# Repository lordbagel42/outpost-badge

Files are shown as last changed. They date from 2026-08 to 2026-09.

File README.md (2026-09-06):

# Outpost badges!



These are e-ink badges that I made for Outpost! They're built with the RP2354 and have an onboard e-ink driver - I also did the art on it :D

Includes:
- 2.9in e-ink screen
- NFC capabilities
- 6 tactile buttons that snap right onto the board
- 15 additional gpio pins broken out to use with the perfboard at the bottom
- USB-C for power and programming
- 3 lanyard holes that fit single + double clip lanyards, and badge clips
- 4 mounting holes in case you want to 3d print a case - see [`case/`](case/) for a printable one

[Here](https://user-cdn.hackclub-assets.com/019ff91c-0464-7b39-83fa-bce072a783c1/img_1220__yafw_balanced_.mp4) is a video of flappy bird on it! Firmware by [@SamDev-7](https://github.com/SamDev-7)

img_1220__yafw_balanced_

You can also use it to play doom (the badge is only used as a monitor + input in this gif) :D

badgedoomgif

---

### PCB + schematic:




---

HUGE thanks to [@cyao](https://github.com/cheyao) for helping with the design, and ordering the boards! The badge would not have worked without the countless reviews and feedback. 

Additional thanks to [@mpkendall](https://github.com/mpkendall) and [@KaiPereira](https://github.com/KaiPereira) for reviewing the board!

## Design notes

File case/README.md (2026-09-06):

# 3D-printable case for the Outpost badge

A two-part, screw-together case generated straight from the KiCad board file.
Designed for a **0.6 mm nozzle**: nothing in it is thinner than 1 mm, which
`tools/check_walls.py` verifies by slicing the exported STLs.

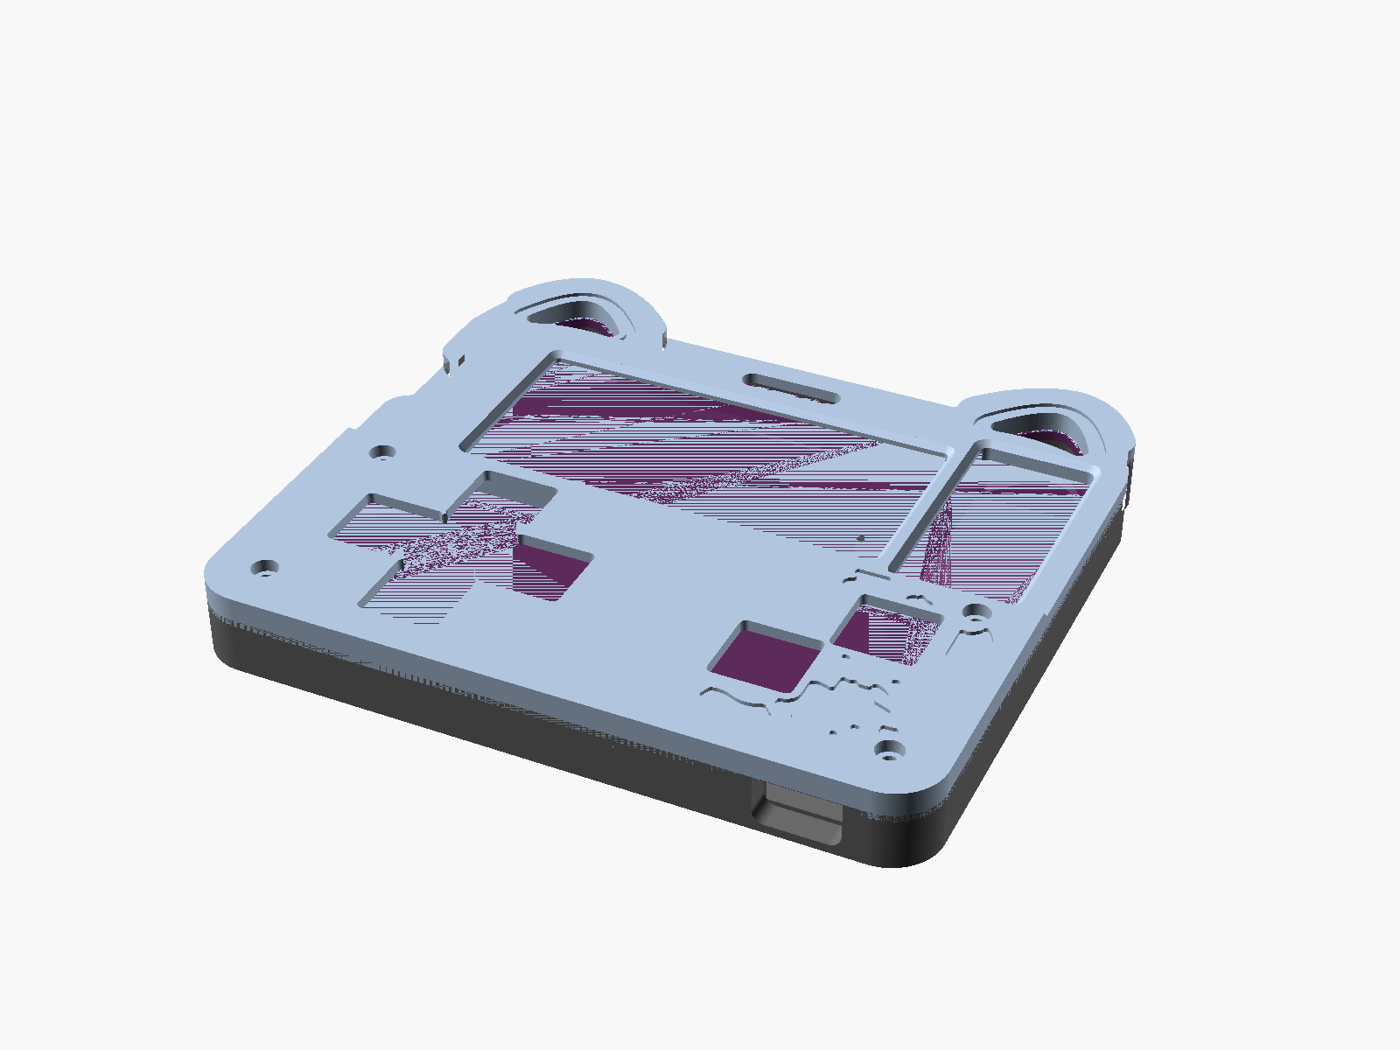
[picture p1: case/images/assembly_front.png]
assembled, front


| Back exterior (as seen from behind, rotated 180°) | Exploded |
| --- | --- |
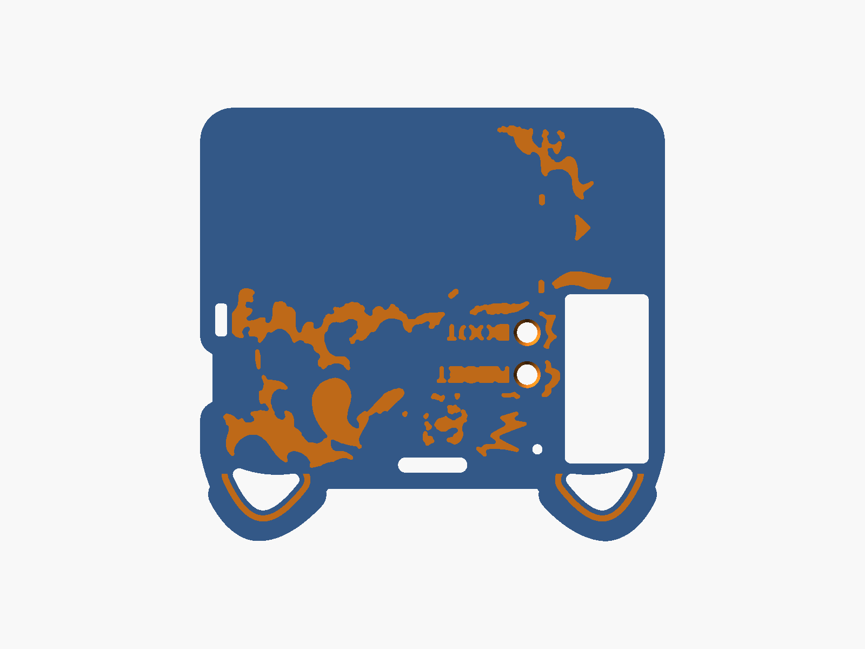
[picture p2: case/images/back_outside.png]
back
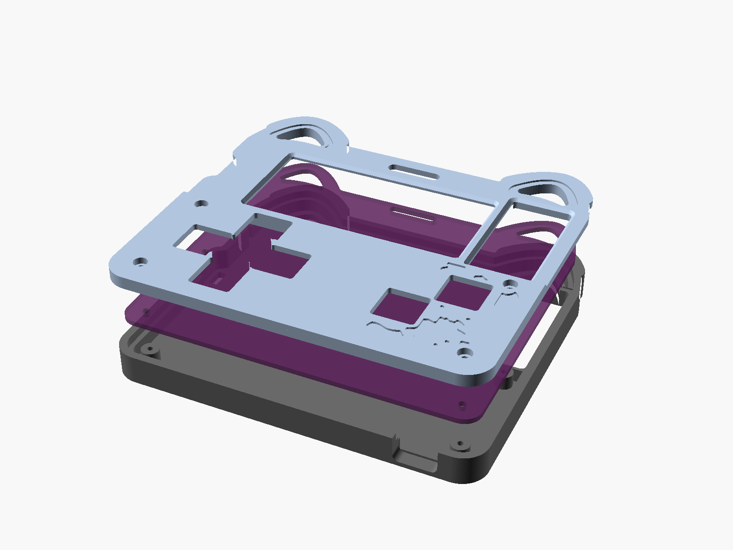
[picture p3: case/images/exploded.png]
exploded
|  |  |

## What it does

* **Removable protoboard cover** with openings for the six 12 mm buttons. The
  switch bodies pass through the cover and the Ø7 mm actuators stand ~3.7 mm
  proud of it. The four D-pad switches sit corner-to-corner, so the island
  between them cannot be printed; the D-pad is one plus-shaped opening with an
  open centre (`dpad_center_open`). A/B are a single joined opening.
* **NFC stays uncovered** on both sides: the front has a window over the whole
  antenna loop (and the flame art inside it), the back has a window over the
  same area, which is where the *OUTPOST* / `hack.club/outpost` QR / *July 14–20
  San Francisco* / Open Sauce block lives. The floor is raised around that
  window so the text sits 0.5 mm behind the print instead of at the bottom of a
  deep pocket.
* **Screen bezel**: a rail all round the e-ink (3.7 mm wide on the NFC side),
  1.8 mm above the glass with a 45° chamfer, 0.8 mm clear of the active area. The bezel sits on the
  PCB outside the module footprint and floats 1.4 mm above the glass; the FPC
  fold on the left edge has its own relief.
* **Back covered and protected**: 4.3 mm cavity under the PCB (USB-C receptacle
  is 3.3 mm, switch pins 3.5 mm), 1.2 mm ledge under the PCB edge, M2 bosses
  under the four mounting holes. Pen-tip holes with `RESET` / `BOOT` labels,
  a light hole for the status LED, a slot over the SWD pads, and a USB-C opening
  sized for the plug overmould (the receptacle face is flush with the PCB edge,
  so the plug has to reach through the wall).
* **Cat ears**: the case follows the PCB ears and grows them by 1.5 mm
  (`ear_boost`), and both faces get a recessed "inner ear" ring around each ear
  slot. All three lanyard cut-outs (two ears + centre slot) go through the
  front, the PCB and the back, so any clip or strap that fits the PCB fits the
  case.
* **Covered artwork is recreated** on the print. Every silkscreen and
  solder-mask polygon that ends up under plastic is engraved 0.6 mm into the
  outer face: on the back that is the red panda and flames, the RESET/BOOT
  swirls, the small cat by the USB port and the *HACK CLUB* flag; on the front
  it is the mascot and *HACK CLUB* flag on the protoboard area and the lightning
  bolts next to the centre slot. The art is filtered for the nozzle: engraved
  strokes narrower than 1 mm are dropped and gaps narrower than 1 mm between
  engraved areas are filled (`min_feature`), so fine line detail becomes
  silhouette. Features under 2 mm (the GPIO pin labels and the PCB's own 1.3 mm
  RESET/BOOT letters) are dropped entirely; RESET/BOOT are re-typed at 4 mm
  beside their holes instead.

## Files

| File | What |
| --- | --- |
| `outpost_badge_case.scad` | The parametric model (OpenSCAD). Open it, use the customizer. |
| `board_data.scad` | Generated board geometry + artwork polygons. Do not edit; regenerate. |
| `tools/extract_board.py` | Reads `PCB/einkbadge.kicad_pcb` and writes `board_data.scad`. |
| `tools/export.sh` | Regenerates the data, all STLs and the preview images. |
| `tools/check_walls.py` | Slices the STLs and lists any solid feature thinner than 1 mm. |
| `stl/back.stl` | Back shell, print orientation. |
| `stl/front.stl` | One-piece front (bezel + ear frame + protoboard cover), print orientation. |
| `stl/front_header_slots.stl` | Same, with slots for pin headers soldered into J3–J6. |
| `stl/split_*.stl` | Alternative three-part version, see below. |

## Printing

Both parts print **face down, no supports**: the back shell exterior on the
bed with the cavity up, the front piece with its visible face on the bed. The
STLs are already in that orientation.

* 0.6 mm nozzle, 0.3 mm layers, 3–4 perimeters, PLA or PETG. Walls are 2.4 mm
  (four lines), the floor 2.1 mm (seven layers), the cover roof 1.8 mm, and no
  rib, ridge or engraved stroke anywhere is under 1 mm, so a 0.6 mm nozzle
  resolves everything. A 0.4 mm nozzle prints it too.
* The artwork is a 0.6 mm recess in the first two layers. For a two-colour
  result add a **filament change at 0.6 mm**: the first colour becomes the face,
  the second shows through as the art, the inner-ear rings and the labels.
* Footprint is about 114 × 106 mm per part. `part = "plate"` puts both on one
  bed (needs ~235 × 110 mm).

## Hardware

* 4 × **M2 × 8 mm** screws (self-tapping or machine screws into the 1.7 mm
  bosses). For heat-set inserts set `screw_hole_d = 3.2`.
* No other hardware. Total stack is 12.8 mm thick.

## Assembly

1. Stick the e-ink module to the PCB as usual and plug in the FPC.
2. Drop the PCB into the back shell, USB-C into its opening. It rests on the
   perimeter ledge and the four bosses.
3. Set the front on top; its rim sits on the wall and the inner plug drops
   inside it. Four M2 screws through the front's counterbores and the PCB's
   mounting holes into the bosses.
4. To get at the protoboard, undo the four screws and lift the front off. The
   PCB stays in the back shell.

## Split front (optional)

`split_front = true` (files `stl/split_*.stl`) makes the screen bezel and the
protoboard cover separate parts, so the cover can come off while the bezel
stays. The bezel sits inside a taller wall and has a tongue under the cover's
top edge, so the four screws clamp it; there is nothing else holding its top
end down, so add a dab of glue at the ears if it rattles. Use `split_back.stl`
with it (the wall is different).

## Assumptions worth checking on a real print

* Screen module thickness 1.4 mm including tape (`screen_h`). If the glass
  touches the bezel underside, raise it.
* Switches are the Würth WS-TATV 430476085716 from the footprint: 12 mm body,
  3.5 mm tall, 8.5 mm overall, 3.5 mm pins. Button openings are 12.8 mm.
* Pin headers J3–J6 are not populated by default; use `front_header_slots.stl`
  if you solder them in.
* PCB clearance 0.3 mm to the wall, 0.15 mm between front plug and wall. Tune
  `clearance` for your printer.

## Regenerating

```sh
pip install shapely            # optional, simplifies the artwork polygons
OPENSCAD=/path/to/openscad-2024+ case/tools/export.sh
pip install trimesh shapely scipy rtree networkx
python3 case/tools/check_walls.py   # thin-wall audit of everything in case/stl
```

If you change a clearance or a window, run the check: it cuts every part at
each 0.3 mm layer and every 4 mm vertically, erodes each slice by 0.5 mm and
reports whatever disappears (with its position), ignoring corner roundings.

OpenSCAD 2024 or newer is strongly recommended: with the Manifold backend each
part renders in a couple of seconds. OpenSCAD 2021.01 renders the same files but
takes many minutes because of the artwork polygons.

All coordinates in the model are millimetres with the origin at the centre of
the PCB, +Y towards the ears and Z = 0 at the PCB top surface, so any position
you read in KiCad is `(x - 204.418, 113.640 - y)`.

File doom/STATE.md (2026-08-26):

# Doom-on-badge port: session state (2026-08-26)

Goal: run Doom natively on the badge's RP2354A, pushing the e-ink as fast as
it can go. **Status: builds and boots on the badge, reproducibly hard-faults
mid `R_Init` — one strong lead to try next (see "Where it stands").**

## What this is

A port of [kilograham/rp2040-doom](https://github.com/kilograham/rp2040-doom)
(branch `defcon32`, the RP2350 DEFCON 32 badge version) to the Outpost badge:

- **Display**: new backend `eink.c` replaces `lcd.c`. Doom's renderer pumps
  320x200 RGB scanlines through `dispRenderLine()`; we downsample to 296x128,
  Bayer-dither to 1-bit, and push frames with the fast-partial-refresh path
  from this repo's `firmware/lib/ssd1680.py` (charge pump held up, old-RAM
  sync via 0x26 after each update, shortened LUT). Waveform: tpa=2,
  frame_rate=0x44, groups=1 → **11.5 fps** panel updates (the fastest setting
  `firmware/epaper/README.md` rates as still visible). The scanline pump is
  self-paced by hardware timer0 alarm **2** (150 µs/line), replacing the
  DEFCON LCD's DMA-IRQ pump. Menu "brightness" is mapped to dither bias.
- **Input**: 6 buttons (U=GP7 L=GP8 R=GP6 D=GP9 A=GP5 B=GP4, active low).
  Chords synthesize the missing DEFCON buttons: A+B=Start(menu),
  L+R=Select(enter), hold U+D=FN (strafe/FPS counter, FN+B cycles weapons).
  **U+D+A+B (and not L/R) = reboot to BOOTSEL** (reflash without the button).
  A chord "poisons" its constituent keys until physically released.
- **Board**: `boards/outpost_badge.h` (PICO_BOARD=outpost_badge), RP2350A,
  2 MB flash. Code at 0x10000000 (<256 KB), WHX-compressed shareware WAD at
  **0x10040000** (1,800,344 bytes, ends 0x101F7898), save games live in the
  ~34 KB above that (found at runtime by flash-aliasing probe — works on 2 MB).

## Files in this directory

- `doom-port.patch` — full diff of branch `outpost` vs `defcon32` in
  rp2040-doom. Apply to a fresh clone of kilograham/rp2040-doom@defcon32.
- `eink.c`, `pinoutOutpost.h`, `outpost_badge.h` — the new files (also in the
  patch; kept separately for readability).
- `apply_port.py` — applies the i_video.c / i_input.c / CMakeLists patches to
  a pristine defcon32 checkout (alternative to the .patch).
- `pack2.py` — **critical**: merges `doom_tiny.uf2` + `doom1.whx` into ONE
  UF2 stream with unified block numbering. Two concatenated UF2s do NOT work:
  the bootloader reboots after the first stream's block count and the WAD
  never lands (cost us one bricked-ish flash).
- `rebuild.sh` — WSL build script (paths assume ~/doom-badge layout below).
- `doom_outpost_full.uf2` — final build: no USB, UART stdio on GP0/GP1,
  save/load enabled. NOT YET TESTED (blocked on the R_Init fault).
- `doom_outpost_usbdebug.uf2` — debug build (`-DHACK_ENABLE_STDIO_USB=1`):
  USB-CDC stdio, **waits for a terminal connection before booting**, no
  save/load, WAD-checksum print at boot, stage prints, pump stats every 3 s.
  This is what is currently flashed on the badge.
- `doomlog.txt` — last captured boot log.

## Build environment (was in WSL Ubuntu on the Windows machine)

```
~/doom-badge/pico-sdk        # tag 2.1.1, lib/tinyusb submodule inited
~/doom-badge/pico-extras     # master (needs *_OVERLAY_SDK_SPINLOCKS defines, already patched in)
~/doom-badge/rp2040-doom     # branch "outpost" (committed), forked from defcon32
~/tools/cmake-3.31.6-linux-x86_64, ~/tools/ninja
```

Configure (from rp2040-doom):
```
cmake -GNinja -DCMAKE_BUILD_TYPE=MinSizeRel -DPICO_SDK_PATH=$HOME/doom-badge/pico-sdk \
  -DPICO_EXTRAS_PATH=$HOME/doom-badge/pico-extras -DPICO_BOARD=outpost_badge \
  -DPICO_BOARD_HEADER_DIRS=$PWD/boards [-DHACK_ENABLE_STDIO_USB=1] ..
ninja doom_tiny
python3 pack2.py build*/src/doom_tiny.uf2 out.uf2   # run from repo root (needs doom1.whx)
```
gcc: distro arm-none-eabi-gcc 13.2. If rebuilding on native Linux, recreate
this layout, apply `doom-port.patch`, and note pico/CMakeLists.txt in the
patch may contain the display-source `if` block twice (harmless duplicate).

## Where it stands — the open bug

Boot log (reproducible, twice):
```
WAD region: 49 57 48 58 checksum 45f35bf3     <- MATCHES host checksum: flash is INTACT
... W_Init OK, "DOOM Shareware" banner, I_Init, M_Init OK ...
R_Init: Init DOOM refresh daemon - .          <- freezes here, USB goes fully dead
```
- USB dying (control transfers time out) while a *panic* keeps USB alive
  (observed with the earlier "No WXD" panic) ⇒ this is a **hard fault on
  core 0**, in exception context, blocking the stdio-USB alarm-pool IRQ.
- It happens before ANY port display/input code runs (I_InitGraphics comes
  after R_Init; input pump later still).
- Flash reads are proven good (full 1.8 MB checksum passes at 270 MHz,
  QMI clkdiv=3 set by i_main.c).

**Top hypothesis (untested): zone memory exhaustion.** `Z_Init` reports only
0x2fce4 (~196 KB) because `src/pico/memmap_doom.ld` still declares
`RAM LENGTH = 256k` (RP2040 value) — but the RP2350 has 520 KB. With
`NO_IERROR=1`, an OOM in R_Init's texture setup doesn't panic; it likely
returns garbage and hard-faults. The port's ~10 KB of static e-ink buffers
shrank the zone below whatever the defcon build had.

**Next step**: in `memmap_doom.ld` set
```
RAM(rwx)      : ORIGIN = 0x20000000, LENGTH = 512k
SCRATCH_X(rwx): ORIGIN = 0x20080000, LENGTH = 4k
SCRATCH_Y(rwx): ORIGIN = 0x20081000, LENGTH = 4k
```
(0x20080000/0x20081000 are the RP2350's real scratch banks; the old
0x20040000 values are plain SRAM addresses that merely worked.)
Rebuild the usbdebug variant, reflash, confirm Z_Init reports a much larger
zone and R_Init completes; expect "eink: dispInit / base refresh done" then
"eink pump: N lines, M frames pushed" every 3 s (M/3 ≈ e-ink fps, target ~11).
If it still faults with a big zone, next suspects: whd texture cache areas
(`USE_MEMMAP_ONLY`, R_InitData paths) — instrument R_Init's sub-steps.

## Flashing / recovery on the physical badge

- Badge currently runs `doom_outpost_usbdebug.uf2`: it waits for a CDC
  terminal, prints the log above, then hard-faults. **USB is dead after the
  fault — only BOOT-button + replug reaches the bootloader.**
- BOOTSEL drive shows as `RP2350`; copy the packed UF2 onto it.
- When a (working) debug build is running, opening its COM port at **1200
  baud** reboots it to BOOTSEL (pico-sdk stdio-USB magic baud). The final
  build has no USB; use the U+D+A+B button combo instead.
- The e-ink may be left with ghosting/garbage after all this. The cure is
  in this repo: `./firmware/tools/deploy.sh recondition` (requires
  CircuitPython on the badge again —
  `adafruit-circuitpython-raspberry_pi_pico2-en_US-10.2.1.uf2` works, and
  `firmware/epaper/examples/badge.py` is the "RAYGEN RUPE" name badge that
  was on the device before the Doom work).

## Serial notes (Windows side; adapt for Linux)

- CDC appeared as COM11; logs captured with .NET SerialPort, DTR+RTS on.
  On Linux it'll be /dev/ttyACM0: `picocom -b 115200 /dev/ttyACM0`.
- The debug build's connect-wait means nothing boots until you open the port.

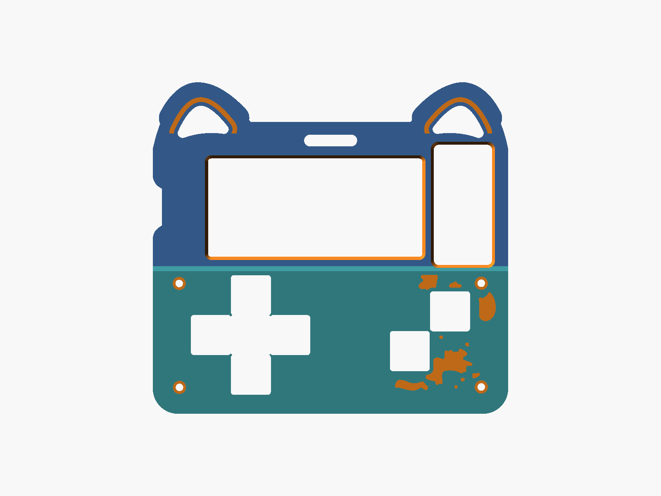
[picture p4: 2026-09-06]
case/images/front_top.png

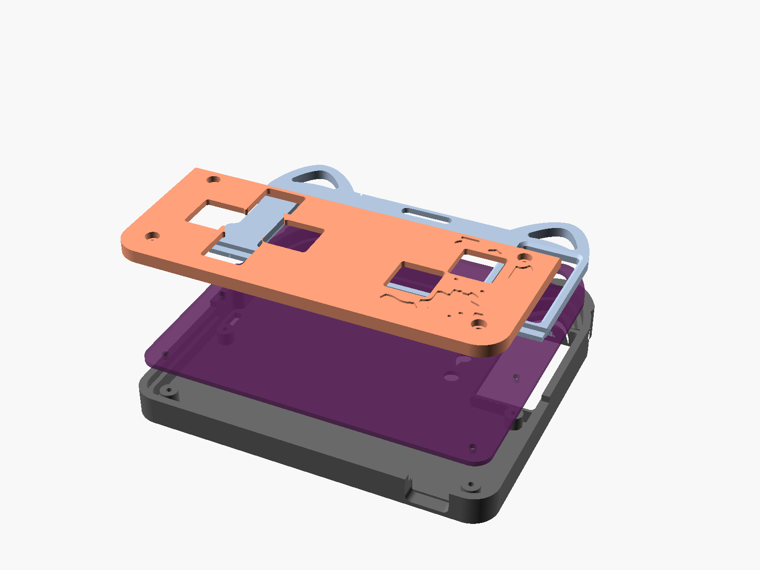
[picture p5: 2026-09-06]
case/images/exploded_split.png

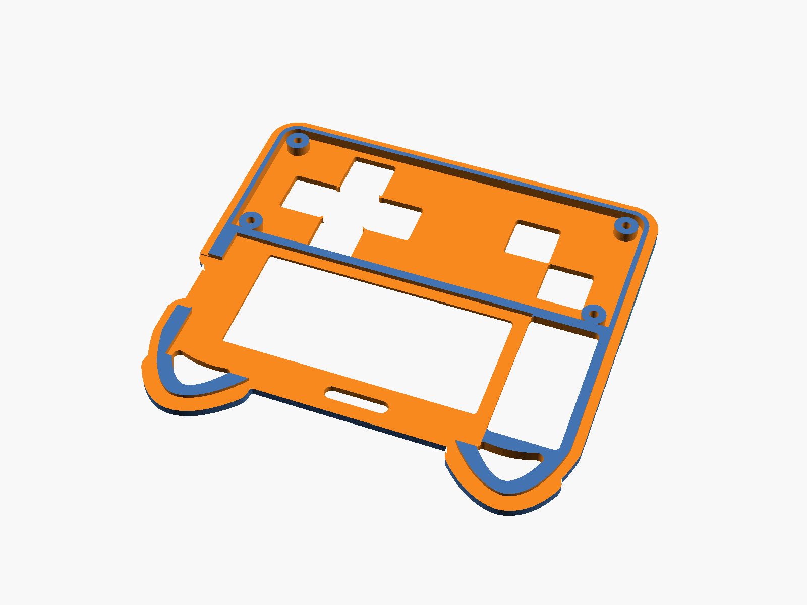
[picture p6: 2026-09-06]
case/images/front_underside.png

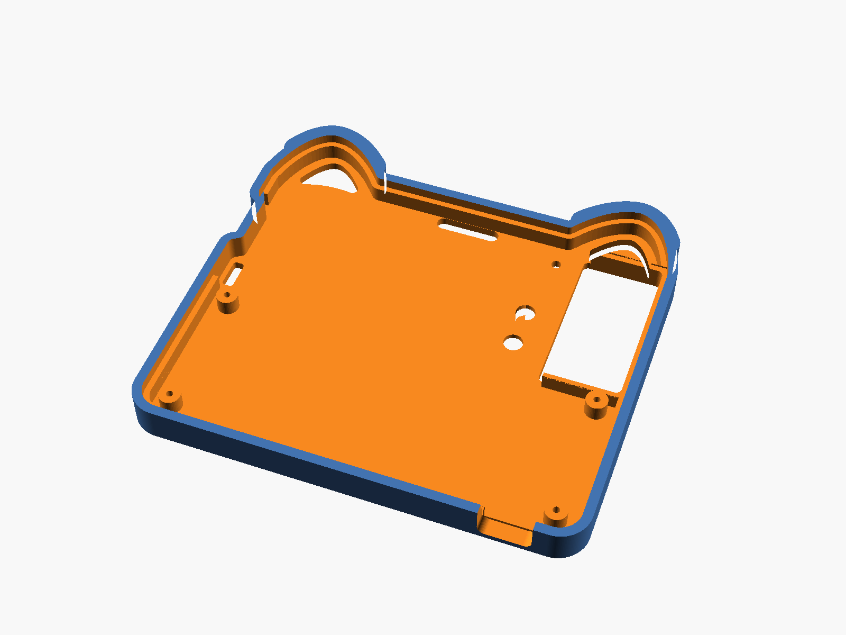
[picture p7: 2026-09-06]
case/images/back_inside.png

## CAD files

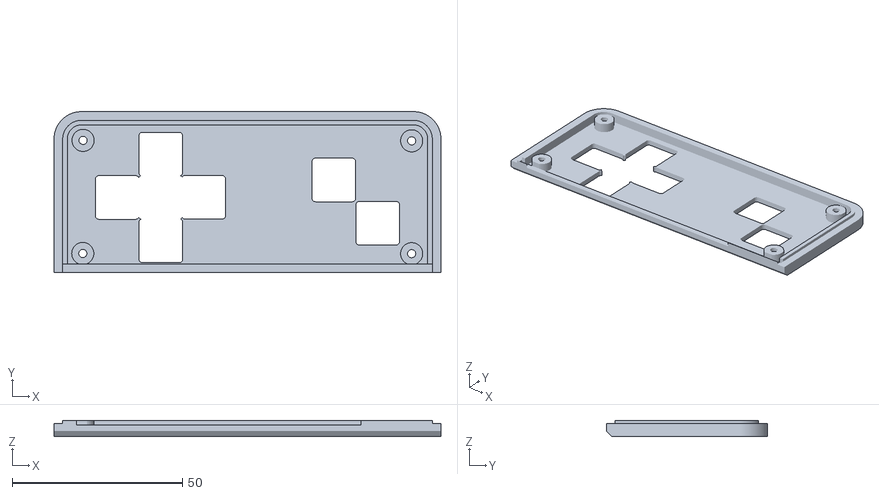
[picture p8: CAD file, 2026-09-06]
case/stl/split_front_cover.stl
113.6 x 47.2 x 4.80

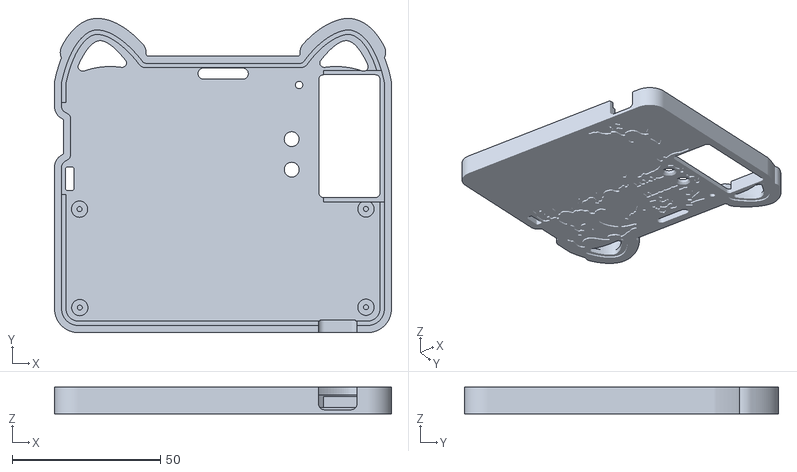
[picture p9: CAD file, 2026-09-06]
case/stl/back.stl
113.6 x 106.0 x 9.00

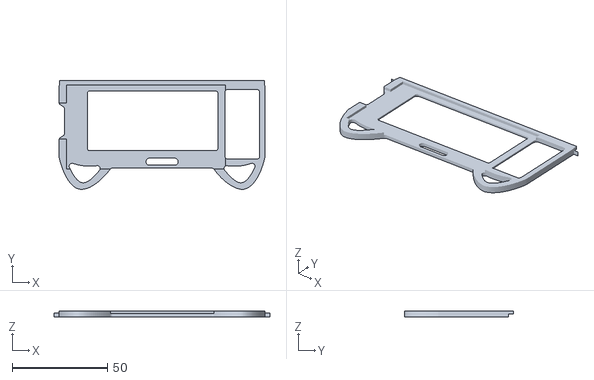
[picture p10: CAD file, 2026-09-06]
case/stl/split_front_bezel.stl
113.6 x 57.2 x 3.20

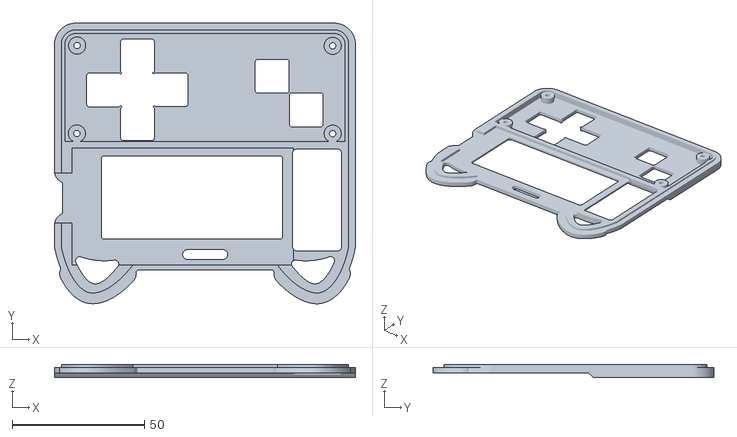
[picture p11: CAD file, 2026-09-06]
case/stl/front.stl
113.6 x 106.0 x 4.80

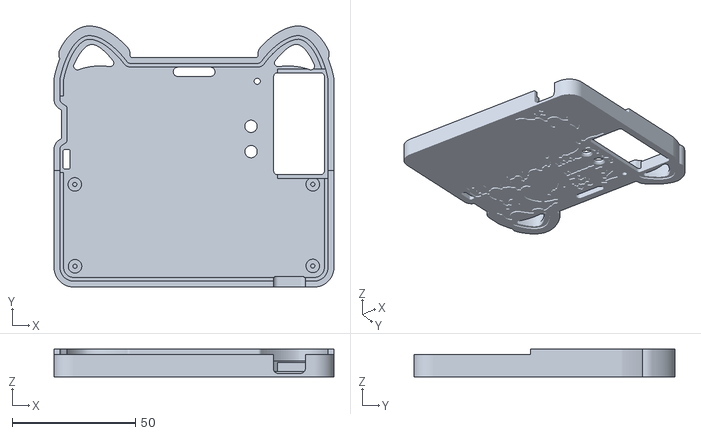
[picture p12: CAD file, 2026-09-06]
case/stl/split_back.stl
113.6 x 106.0 x 11.2

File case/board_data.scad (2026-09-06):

// GENERATED by case/tools/extract_board.py from PCB/einkbadge.kicad_pcb
// Do not edit by hand.  Units: mm.  Origin: centre of the PCB bounding box,
// +Y towards the cat ears, +Z towards the front (screen) side.

pcb_thickness = 1.6;
board_size = [108.228, 99.0718];
ear_base_y = 38.281;  // Y of the straight top edge between the ears
ear_tip_y = 49.5359;

board_outline = [[42.6244,49.5324],[43.2523,49.4192],[43.8618,49.2498],[44.4532,49.027],[45.0264,48.7536],[45.5816,48.4325],[46.1189,48.0664],[46.6382,47.6584],[47.1399,47.2112],[47.6238,46.7276],[48.0902,46.2105],[48.5391,45.6628],[48.9705,45.0873],[49.3847,44.4868],[49.7816,43.8643],[50.5243,42.5642],[51.1991,41.2098],[51.8069,39.8239],[52.3484,38.4292],[52.8243,37.0486],[53.2353,35.7048],[53.5822,34.4206],[53.8658,33.2187],[54.0866,32.1219],[54.0932,32.0834],[54.0988,32.045],[54.1035,32.0066],[54.1073,31.9682],[54.1102,31.9298],[54.1123,31.8912],[54.1135,31.8524],[54.1139,31.8133],[54.1139,-28.7],[54.1139,-44.1781],[54.1069,-44.4538],[54.0862,-44.7259],[54.0522,-44.994],[54.0051,-45.2579],[53.9452,-45.5171],[53.873,-45.7713],[53.7888,-46.0203],[53.6929,-46.2636],[53.5856,-46.5009],[53.4673,-46.7319],[53.3382,-46.9563],[53.1989,-47.1737],[53.0495,-47.3838],[52.8904,-47.5862],[52.7221,-47.7806],[52.5446,-47.9666],[52.3586,-48.144],[52.1642,-48.3124],[51.9618,-48.4715],[51.7517,-48.6209],[51.5343,-48.7602],[51.31,-48.8892],[51.0789,-49.0076],[50.8416,-49.1149],[50.5983,-49.2108],[50.3494,-49.295],[50.0951,-49.3672],[49.8359,-49.4271],[49.572,-49.4742],[49.3039,-49.5082],[49.0318,-49.5289],[48.7561,-49.5359],[-48.7561,-49.5359],[-49.0318,-49.5289],[-49.3039,-49.5082],[-49.572,-49.4742],[-49.8359,-49.4271],[-50.0951,-49.3672],[-50.3493,-49.295],[-50.5983,-49.2108],[-50.8416,-49.1149],[-51.0789,-49.0076],[-51.3099,-48.8892],[-51.5343,-48.7602],[-51.7517,-48.6209],[-51.9618,-48.4715],[-52.1642,-48.3124],[-52.3586,-48.144],[-52.5446,-47.9666],[-52.722,-47.7806],[-52.8904,-47.5862],[-53.0495,-47.3838],[-53.1989,-47.1737],[-53.3382,-46.9563],[-53.4672,-46.7319],[-53.5856,-46.5009],[-53.6929,-46.2636],[-53.7888,-46.0203],[-53.873,-45.7713],[-53.9452,-45.5171],[-54.0051,-45.2579],[-54.0522,-44.994],[-54.0862,-44.7259],[-54.1069,-44.4538],[-54.1139,-44.1781],[-54.1139,3.6251],[-54.1104,3.7371],[-54.1,3.8479],[-54.0828,3.9572],[-54.059,4.0647],[-54.0287,4.1702],[-53.9921,4.2733],[-53.9494,4.3739],[-53.9006,4.4715],[-53.846,4.566],[-53.7856,4.657],[-53.7197,4.7444],[-53.6484,4.8277],[-53.5717,4.9068],[-53.49,4.9814],[-53.4033,5.0511],[-53.3117,5.1157],[-51.9395,6.0214],[-51.848,6.086],[-51.7613,6.1557],[-51.6795,6.2303],[-51.6029,6.3093],[-51.5315,6.3927],[-51.4656,6.48],[-51.4053,6.5711],[-51.3506,6.6656],[-51.3019,6.7632],[-51.2591,6.8638],[-51.2225,6.9669],[-51.1923,7.0724],[-51.1685,7.1799],[-51.1513,7.2892],[-51.1408,7.3999],[-51.1373,7.5119],[-51.1373,20.1419],[-51.1411,20.2572],[-51.1521,20.3712],[-51.1703,20.4835],[-51.1955,20.594],[-51.2275,20.7022],[-51.2662,20.8078],[-51.3113,20.9107],[-51.3628,21.0104],[-51.4204,21.1067],[-51.484,21.1993],[-51.5535,21.2879],[-51.6286,21.3721],[-51.7092,21.4517],[-51.7951,21.5264],[-51.8861,21.5958],[-51.9822,21.6598],[-53.269,22.4576],[-53.3177,22.4889],[-53.3651,22.5215],[-53.4113,22.5556],[-53.4562,22.591],[-53.4998,22.6277],[-53.5421,22.6656],[-53.6227,22.7452],[-53.6978,22.8295],[-53.7672,22.918],[-53.8308,23.0106],[-53.8885,23.1069],[-53.9399,23.2066],[-53.9851,23.3094],[-54.0238,23.4151],[-54.0558,23.5233],[-54.081,23.6338],[-54.0909,23.6897],[-54.0991,23.7461],[-54.1056,23.8029],[-54.1102,23.8601],[-54.113,23.9176],[-54.1139,23.9754],[-54.1139,31.9579],[-54.1132,32.0057],[-54.1113,32.0537],[-54.108,32.1018],[-54.1034,32.1498],[-54.0975,32.1977],[-54.0904,32.2453],[-54.082,32.2926],[-54.0723,32.3394],[-53.4869,34.7496],[-52.8478,36.9373],[-52.1635,38.9119],[-51.4427,40.6828],[-50.6937,42.2595],[-49.9252,43.6514],[-49.1457,44.8678],[-48.3636,45.9181],[-47.5876,46.8119],[-46.8262,47.5584],[-46.0879,48.1671],[-45.3811,48.6475],[-44.7146,49.0088],[-44.0967,49.2605],[-43.536,49.412],[-43.0411,49.4728],[-42.4888,49.5018],[-41.9325,49.4894],[-41.3731,49.4372],[-40.8114,49.3473],[-40.2481,49.2215],[-39.6841,49.0616],[-39.1201,48.8695],[-38.5571,48.647],[-37.9957,48.396],[-37.4367,48.1184],[-36.3296,47.4906],[-35.2419,46.7786],[-34.1803,45.9971],[-33.151,45.161],[-32.1606,44.2852],[-31.2155,43.3845],[-30.322,42.4738],[-29.4867,41.568],[-28.7159,40.6818],[-28.0161,39.8302],[-27.3937,39.028],[-27.326,38.9432],[-27.254,38.8627],[-27.178,38.7868],[-27.0981,38.7156],[-27.0147,38.6492],[-26.9278,38.5878],[-26.8378,38.5315],[-26.7449,38.4805],[-26.6492,38.435],[-26.5511,38.395],[-26.4507,38.3608],[-26.3483,38.3324],[-26.244,38.3101],[-26.1381,38.294],[-26.0309,38.2842],[-25.9225,38.281],[26.0381,38.281],[26.1469,38.2843],[26.2545,38.2942],[26.3608,38.3105],[26.4655,38.3332],[26.5683,38.3619],[26.6691,38.3966],[26.7675,38.4371],[26.8634,38.4833],[26.9565,38.535],[27.0466,38.592],[27.1333,38.6543],[27.2166,38.7216],[27.2961,38.7938],[27.3716,38.8707],[27.4429,38.9522],[27.5097,39.0382],[28.7061,40.5972],[29.8949,42.0033],[31.0708,43.2634],[32.228,44.3846],[33.361,45.3737],[34.4642,46.2378],[35.532,46.9838],[36.5588,47.6187],[37.5389,48.1494],[38.4668,48.5829],[39.3369,48.9261],[40.1436,49.1861],[40.8813,49.3697],[41.5444,49.484],[42.1273,49.5359]];
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

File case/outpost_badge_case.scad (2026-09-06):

// Outpost badge - 3D printable case
// ==================================
// Parametric OpenSCAD model.  All board geometry (outline, cat ears, lanyard
// slots, button positions, mounting holes, screen, NFC antenna, USB-C, back-side
// buttons and the silkscreen/mask artwork) comes from board_data.scad, which is
// generated from PCB/einkbadge.kicad_pcb by tools/extract_board.py.
//
// Parts
//   back   - tray the PCB drops into.  Covers and protects all back-side
//            components, has a window over the OUTPOST / QR / date / Open Sauce
//            text block (which is also the NFC antenna area), access holes for
//            RESET / BOOT and the status LED, the USB-C port, the three lanyard
//            slots and M2 screw bosses under the four PCB mounting holes.
//   front  - one piece (default): screen bezel + cat-ear frame + removable
//            protoboard cover with openings for the six 12 mm buttons (and the
//            pin-header rows).  Held by four M2 screws through the PCB holes.
//            Leaves the NFC antenna uncovered.
//   Covered PCB artwork is recreated on the print as a 0.6 mm recess (or an
//   emboss) so a two-colour print reproduces it.
//
// Coordinates: mm, origin = centre of the PCB, +Y towards the ears, Z = 0 at
// the PCB top (screen side) surface, +Z towards the viewer of the screen.
//
// Designed for a 0.6 mm nozzle / 0.3 mm layers: no wall, rib or engraved
// feature is thinner than min_feature (1.0 mm) anywhere in the model.
//
// Recommended: OpenSCAD 2024+ (Manifold backend).  2021.01 works but is slow.

include <board_data.scad>

/* [Part] */
// Which part to generate
part = "assembly"; // [assembly, exploded, back, front, front_bezel, front_cover, plate]
// Lay single parts flat in their print orientation (face down)
print_orientation = false;
// Split the front into a separate screen bezel and protoboard cover
split_front = false;
// Show a translucent PCB in the assembly views
show_pcb = true;

/* [Shell] */
// Wall thickness (4 lines of a 0.6 mm nozzle)
wall = 2.4;
// Gap between PCB edge and wall
clearance = 0.3;
// Back floor thickness (art recess is cut into this, 7 layers of 0.3 mm)
floor_t = 2.1;
// Free height under the PCB (USB-C 3.3 mm, switch pins 3.5 mm)
back_cavity = 4.3;
// How far the wall rises above the PCB top surface
lip_h = 1.0;
// Width of the ledge under the PCB edge
ledge_w = 1.2;

/* [Front] */
// Thickness of the e-ink module incl. adhesive
screen_h = 1.4;
// Bezel thickness above the screen glass
bezel_t = 1.8;
// Gap between the bezel opening and the screen active area
window_clear = 0.8;
// 45 degree chamfer on the bezel opening
bezel_chamfer = 1.0;
// Free height above the PCB under the protoboard cover
cover_inner = 3.0;
// Protoboard cover roof thickness
roof_t = 1.8;
// Gap around each 12 mm button body
button_clear = 0.4;
// Open the centre of the D-pad (the island between the four buttons cannot be printed)
dpad_center_open = true;
// Cut slots for the pin-header rows (J3..J6).  Needed if you solder headers into the protoboard.
header_slots = false;
// Gap around the header pad rows
header_clear = 0.6;
// Width of the cover rim that rests on the PCB inside the wall
cover_rim = 1.2;

/* [Cat ears] */
// Grow the ears of the case beyond the PCB ears (0 = follow the PCB)
ear_boost = 1.5;
// Width of the "inner ear" recess ring around each ear slot
ear_ring_w = 1.5;
// Wall between slot edge and inner-ear ring
ear_ring_gap = 1.2;

/* [Artwork] */
// recess = engraved 0.6 mm (prints face down, no supports).  emboss = raised (needs the exterior face up).
art_mode = "recess"; // [recess, emboss, none]
// Depth / height of the recreated artwork
art_depth = 0.6;
// Drop artwork features smaller than this (tiny text is not printable)
art_min = 2.0;
// Fatten thin strokes by this much before filtering
art_grow = 0.1;
// Smallest printable feature: engraved strokes narrower than this are dropped and
// ridges between engravings narrower than this are filled (1.0 for a 0.6 mm nozzle)
min_feature = 1.0;
// Keep artwork this far from openings and edges
art_margin = 1.2;
// Recreate the RESET / BOOT labels as legible text (the PCB's 1.3 mm letters are too small to print)
back_labels = true;
label_size = 4.0;

/* [Fasteners] */
// Hole in the back bosses: 1.7 = M2 thread-forming into plastic, 3.2 = M2 heat-set insert
screw_hole_d = 1.7;
// Boss diameter in the back shell
boss_d = 5.5;
// Clearance hole for the M2 shank through the front
screw_shank_d = 2.4;
// Counterbore for the M2 head
screw_head_d = 4.2;
screw_head_h = 2.0;
// Column diameter around the screw inside the cover (>= screw_head_d + 2 * min_feature)
front_col_d = 6.5;

/* [Openings] */
// USB-C opening (sized for the plug overmould, connector face is flush with the PCB edge)
usb_w = 13.0;
usb_h = 6.8;
// Extra clearance around the lanyard slots
slot_clear = 0.5;
// Pen-tip access holes for RESET / BOOT on the back
back_button_hole_d = 5.0;
// Light hole for the status LED on the back
led_hole_d = 2.5;
// Slot in the floor over the SWD header pads
swd_slot = true;
// Corner radius of the back text/NFC window
window_r = 1.5;

/* [Hidden] */
$fn = 48;
eps = 0.01;
pcb_t = pcb_thickness;
z_pcb_bot = -pcb_t;
z_floor_top = z_pcb_bot - back_cavity;
z_floor_bot = z_floor_top - floor_t;
frame_top = screen_h + bezel_t;             // top face of bezel / ear frame
cover_top = cover_inner + roof_t;           // top face of the protoboard cover
seam_y = screen_module[1] - 0.6;            // bezel / cover boundary (just below the glass)
band = 2.5;                                 // solid band between the glass and the cover cavity
cavity_y = seam_y - band;                   // cover cavity starts here
mesa_gap = 0.5;                             // floor rises to this distance under the PCB around the back window
screw_depth = back_cavity + 0.7;            // thread depth into the boss (+ a bit into the floor)
bezel_fit = 0.15;                           // gap between a split bezel and the wall

board_xmin = min([for (p = board_outline) p[0]]);
board_xmax = max([for (p = board_outline) p[0]]);
board_ymin = min([for (p = board_outline) p[1]]);
board_ymax = max([for (p = board_outline) p[1]]);
ear_slots = [for (s = lanyard_slots) if (max([for (p = s) p[1]]) > ear_base_y) s];
dpad = [for (b = buttons) if (b[0] == "SW1" || b[0] == "SW2" || b[0] == "SW3" || b[0] == "SW4") b[1]];
dpad_center = [(dpad[0][0] + dpad[1][0] + dpad[2][0] + dpad[3][0]) / 4,
               (dpad[0][1] + dpad[1][1] + dpad[2][1] + dpad[3][1]) / 4];

// Lowest point of the ear lanyard slots (with clearance): the windows below must
// leave at least min_feature (+ the bezel chamfer on the front) of material to it.
ear_slot_bottom = min([for (s = ear_slots) for (p = s) p[1]]) - slot_clear;
// Front NFC window: the antenna loop plus the art around it, up to the ear slots
// and out towards the board edge (leaving a >= 1 mm rim after the chamfer).
nfc_window = [nfc_rect[0] - 0.1,
              seam_y + (split_front ? min_feature + 0.2 + bezel_chamfer : 0.4),
              board_xmax - 1.5 - bezel_chamfer - (split_front ? 0.2 : 0),
              ear_slot_bottom - min_feature - 0.2 - bezel_chamfer];
// Back window: OUTPOST / QR / dates / Open Sauce block (same area as the antenna)
back_window = [nfc_rect[0] - 0.8, seam_y - 1.6, board_xmax - 1.2, ear_slot_bottom - min_feature - 0.2];
back_mesa_xmin = back_window[0] + 1.5;      // no raised rim on the left (components there)
// The screen pocket is extended up to the centre lanyard slot and down to the seam so no
// sliver of frame is left standing on the PCB between the pocket and a cut-out.
slot_top_y = max([for (s = lanyard_slots) for (p = s) if (p[1] < ear_base_y) p[1]]);
pocket_rect = [screen_module[0] - 0.4, seam_y - 0.1,
               max(screen_module[2] + 0.4, nfc_window[0] + 0.3),   // run into the NFC window: no sliver between them
               slot_top_y + slot_clear + 0.3];

// ------------------------------------------------------------ 2D helpers ---
module rect(r) translate([r[0], r[1]]) square([r[2] - r[0], r[3] - r[1]]);
module rrect(r, rad) offset(r = rad) offset(delta = -rad) rect(r);
function grown(r, d) = [r[0] - d, r[1] - d, r[2] + d, r[3] + d];
module rsq(s, rad) offset(r = rad) offset(delta = -rad) square(s, center = true);
module below(y) translate([-300, y - 600]) square([600, 600]);
module above(y) translate([-300, y]) square([600, 600]);
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

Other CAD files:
case/stl/front_header_slots.stl

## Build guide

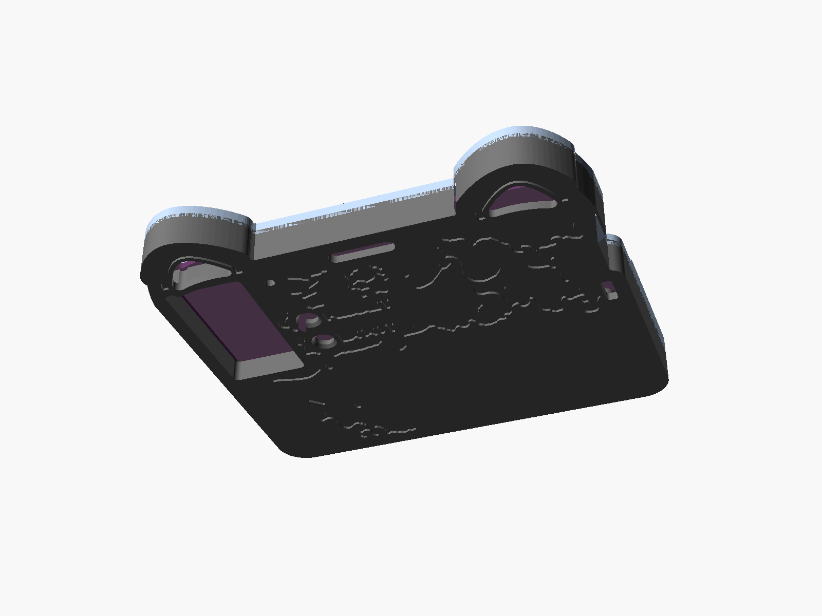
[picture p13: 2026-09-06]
case/images/assembly_back.png

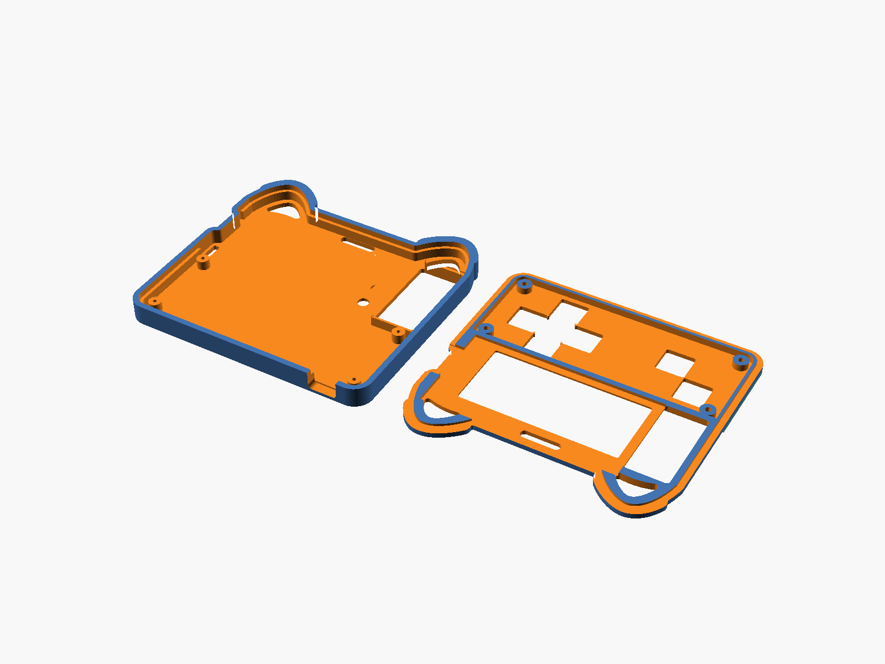
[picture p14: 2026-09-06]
case/images/print_plate.png

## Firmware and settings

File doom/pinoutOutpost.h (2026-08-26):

#ifndef _PINOUT_OUTPOST_H_
#define _PINOUT_OUTPOST_H_

// Outpost badge (RP2354A + SSD1680 2.9" e-ink), pin map from the badge
// firmware README / KiCad netlist.

#define PIN_EPD_CS      13
#define PIN_EPD_SCK     14      // SPI1 SCK
#define PIN_EPD_MOSI    15      // SPI1 TX
#define PIN_EPD_BUSY    16      // high = busy
#define PIN_EPD_DC      17
#define PIN_EPD_RST     18      // active low

#define PIN_BTN_U       7
#define PIN_BTN_L       8
#define PIN_BTN_R       6
#define PIN_BTN_D       9
#define PIN_BTN_A       5
#define PIN_BTN_B       4

// hardware alarm used to pace the scanline pump (alarm pool is disabled)
#define EINK_ALARM_NUM  3

#endif

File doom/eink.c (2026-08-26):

/*
 * SSD1680 e-ink display backend for rp2040-doom on the Outpost badge.
 *
 * Implements the same interface as lcd.c (lcd.h): the doom renderer pumps
 * 320-pixel RGB scanlines through dispRenderLine(); we dither them into a
 * 1-bit 296x128 framebuffer and push complete frames to the panel with the
 * badge firmware's fast-partial-refresh path (custom short LUT, charge pump
 * held up, old-RAM kept in sync).
 *
 * The scanline pump is self-paced with a hardware timer alarm: each
 * dispRenderLine() call arms the alarm, whose IRQ calls fill_scanlines()
 * again (on the DEFCON32 LCD this role was played by the line-DMA IRQ).
 *
 * Waveform setting: tpa=2, frame_rate=0x44, groups=1 -> ~80ms panel time,
 * measured 11.5 fps on this panel ("slightly worse" contrast than the
 * 9.4 fps milestone setting; see the badge repo epaper/README.md).
 * Dropping the group-1 hold pulse also removes the static-pixel bias, so
 * this is the panel-safe end of the fast settings.
 */

#include <stdio.h>
#include <string.h>
#include "pico/stdlib.h"
#include "hardware/spi.h"
#include "hardware/gpio.h"
#include "hardware/irq.h"
#include "hardware/structs/timer.h"
#include "pinoutOutpost.h"
#include "lcd.h"
#include "doom/doomstat.h"      // brightnessLevel

#define EPD_SPI         spi1
#define EPD_BAUD        20000000

// Panel geometry: RAM rows run along the 296 axis; 128 bits per row.
#define EPD_COLS        128
#define EPD_ROWS        296
#define EPD_STRIDE      (EPD_COLS / 8)          // 16 bytes per row
#define EPD_BUFLEN      (EPD_STRIDE * EPD_ROWS) // 4736 bytes

// Doom source frame
#define SRC_W           320
#define SRC_H           200

// Scanline pump period. 150us x 200 lines = 30ms/frame (~33 fps pump),
// same ballpark as the DEFCON32 LCD line rate.
#define LINE_US         150

// Waveshare WF_PARTIAL for the SSD1680 (153 LUT bytes + 6 config bytes),
// same table as the badge firmware's ssd1680.py.
static const uint8_t wf_partial[159] = {
    0x00, 0x40, 0x00, 0x00, 0x00, 0x00, 0x00, 0x00, 0x00, 0x00, 0x00, 0x00,
    0x80, 0x80, 0x00, 0x00, 0x00, 0x00, 0x00, 0x00, 0x00, 0x00, 0x00, 0x00,
    0x40, 0x40, 0x00, 0x00, 0x00, 0x00, 0x00, 0x00, 0x00, 0x00, 0x00, 0x00,
    0x00, 0x80, 0x00, 0x00, 0x00, 0x00, 0x00, 0x00, 0x00, 0x00, 0x00, 0x00,
    0x00, 0x00, 0x00, 0x00, 0x00, 0x00, 0x00, 0x00, 0x00, 0x00, 0x00, 0x00,
    0x0A, 0x00, 0x00, 0x00, 0x00, 0x00, 0x01,
    0x01, 0x00, 0x00, 0x00, 0x00, 0x00, 0x00,
    0x01, 0x00, 0x00, 0x00, 0x00, 0x00, 0x00,
    0x00, 0x00, 0x00, 0x00, 0x00, 0x00, 0x00,
    0x00, 0x00, 0x00, 0x00, 0x00, 0x00, 0x00,
    0x00, 0x00, 0x00, 0x00, 0x00, 0x00, 0x00,
    0x00, 0x00, 0x00, 0x00, 0x00, 0x00, 0x00,
    0x00, 0x00, 0x00, 0x00, 0x00, 0x00, 0x00,
    0x00, 0x00, 0x00, 0x00, 0x00, 0x00, 0x00,
    0x00, 0x00, 0x00, 0x00, 0x00, 0x00, 0x00,
    0x00, 0x00, 0x00, 0x00, 0x00, 0x00, 0x00,
    0x00, 0x00, 0x00, 0x00, 0x00, 0x00, 0x00,
    0x22, 0x22, 0x22, 0x22, 0x22, 0x22, 0x00, 0x00, 0x00,
    0x22, 0x17, 0x41, 0xB0, 0x32, 0x36,
};

// speed/contrast trade (see epaper/README.md in the badge repo)
#define WF_TPA          2       // group 0 drive frames
#define WF_FRAME_RATE   0x44
#define WF_GROUPS       1       // drop group 1 hold pulse + group 2

static uint8_t fb_accum[EPD_BUFLEN];    // dither target (bit 1 = white)
static uint8_t fb_sent[EPD_BUFLEN];     // snapshot on the panel / in old RAM

static volatile enum { EPD_IDLE, EPD_UPDATING } epd_state;
static volatile bool frame_dirty;       // a complete new frame is in fb_accum
static int dither_bias;                 // from dispSetBrightness()

// source-line -> target-row map: 0xFF = line not sampled
static uint8_t line_target[SRC_H];
// target-column -> source-pixel map
static uint16_t xmap[EPD_ROWS];

static const uint8_t bayer4[16] = {
    0, 8, 2, 10,
    12, 4, 14, 6,
    3, 11, 1, 9,
    15, 7, 13, 5,
};

extern void fill_scanlines(void);

// debug counters, printed from the core-0 input poll
volatile uint32_t eink_lines_pumped, eink_frames_pushed;

// verify the flashed WHX region before anything parses it (called from i_main)
void outpost_wad_check(void) {
#ifdef TINY_WAD_ADDR
    const uint8_t *w = (const uint8_t *) TINY_WAD_ADDR;
    uint32_t sum = 0;
    for (uint32_t i = 0; i < 1800344; i++) sum = sum * 31 + w[i];
    printf("WAD region: %02x %02x %02x %02x checksum %08x\n",
           w[0], w[1], w[2], w[3], (unsigned) sum);
#endif
}

// ---- low-level panel access -------------------------------------------

static void __not_in_flash_func(epd_cmd)(uint8_t cmd, const uint8_t *data, size_t n) {
    gpio_put(PIN_EPD_DC, 0);
    gpio_put(PIN_EPD_CS, 0);
    spi_write_blocking(EPD_SPI, &cmd, 1);
    gpio_put(PIN_EPD_CS, 1);
    if (n) {
        gpio_put(PIN_EPD_DC, 1);
        gpio_put(PIN_EPD_CS, 0);
        spi_write_blocking(EPD_SPI, data, n);
        gpio_put(PIN_EPD_CS, 1);
    }
}

static void epd_cmd1(uint8_t cmd, uint8_t d0) { epd_cmd(cmd, &d0, 1); }

static inline bool epd_busy(void) { return gpio_get(PIN_EPD_BUSY); }

static void epd_wait(void) {
    absolute_time_t deadline = make_timeout_time_ms(15000);
    while (epd_busy() && !time_reached(deadline)) tight_loop_contents();
}

static void epd_reset(void) {
    gpio_put(PIN_EPD_RST, 1); busy_wait_ms(20);
    gpio_put(PIN_EPD_RST, 0); busy_wait_ms(5);
    gpio_put(PIN_EPD_RST, 1); busy_wait_ms(20);
    epd_wait();
}

static void epd_set_window_full(void) {
    static const uint8_t xw[2] = { 0, EPD_STRIDE - 1 };
    static const uint8_t yw[4] = { 0, 0, (EPD_ROWS - 1) & 0xFF, (EPD_ROWS - 1) >> 8 };
    static const uint8_t zero1[1] = { 0 };
    static const uint8_t zero2[2] = { 0, 0 };
    epd_cmd(0x44, xw, 2);
    epd_cmd(0x45, yw, 4);
    epd_cmd(0x4E, zero1, 1);
    epd_cmd(0x4F, zero2, 2);
}

static void epd_init_regs(void) {
    epd_reset();
    epd_cmd(0x12, NULL, 0);             // SW reset -> factory LUT from OTP
    epd_wait();
    {
        const uint8_t d[3] = { (EPD_ROWS - 1) & 0xFF, (EPD_ROWS - 1) >> 8, 0x00 };
        epd_cmd(0x01, d, 3);            // driver output control
    }
    epd_cmd1(0x11, 0x03);               // data entry: X inc, Y inc
    epd_set_window_full();
    epd_cmd1(0x3C, 0x05);               // border waveform
    epd_cmd1(0x18, 0x80);               // internal temperature sensor
    {
        const uint8_t d[2] = { 0x00, 0x80 };
        epd_cmd(0x21, d, 2);            // display update control 1
    }
    epd_wait();
}

static void epd_load_lut(void) {
    uint8_t lut[159];
    memcpy(lut, wf_partial, sizeof lut);
    lut[60] = WF_TPA;                   // group 0 phase-A frame count
    for (int i = 144; i < 150; i++) lut[i] = WF_FRAME_RATE;
    if (WF_GROUPS < 3) lut[60 + 14] = 0;
    if (WF_GROUPS < 2) lut[60 + 7] = 0;
    epd_cmd(0x32, lut, 153);
    epd_cmd1(0x3F, lut[153]);
    epd_cmd1(0x03, lut[154]);           // gate voltage
    epd_cmd(0x04, &lut[155], 3);        // source VSH1/VSH2/VSL
    epd_cmd1(0x2C, lut[158]);           // VCOM
    epd_wait();
}
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

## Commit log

2026-09-06 Add 3D-printable case generated from the KiCad board
    Parametric OpenSCAD case for the badge, with the geometry pulled straight
    out of PCB/einkbadge.kicad_pcb by case/tools/extract_board.py:
    - Back shell: protects the back-side parts, M2 bosses under the four
    mounting holes, window over the OUTPOST / QR / date block (also the NFC
    antenna area), RESET/BOOT pen holes with labels, LED and SWD openings,
    USB-C opening, all three lanyard slots.
    - Front: screen bezel with chamfered opening, cat-ear frame with the ears
    grown 1.5 mm and inner-ear rings, and a screw-on protoboard cover with
    openings for the six 12 mm buttons (optional pin-header slots). NFC
    antenna stays uncovered.
    - Cove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
    [back.stl, board_data.scad, front.stl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]
2026-09-06 Make the case printable with a 0.6 mm nozzle (no feature under 1 mm)
    - Walls 2.4 mm, floor 2.1 mm, screw columns 6.5 mm, wider cover rim and
    inner-ear ring gap, USB opening trimmed so the floor under it stays
    >= 1 mm.
    - Screen pocket now runs into the NFC window and up to the centre slot,
    removing 0.2 mm slivers standing on the PCB; windows are kept
    >= 1 mm (+ chamfer) away from the ear lanyard slots.
    - Engraved artwork is filtered with a 1 mm morphological closing/opening
    so no groove or ridge is narrower than 1 mm; RESET/BOOT labels re-typed
    at 4 mm beside the holes.
    - Split variant: tongue confined inside the wall, no ear ring on the
    bezel (no margin for it), NFC window rim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
    [back.stl, front.stl, front_header_slots.stl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]
